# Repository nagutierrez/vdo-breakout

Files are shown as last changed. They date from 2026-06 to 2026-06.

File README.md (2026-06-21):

# VDO Breakout

A 4-gauge breakout board for VDO automotive instruments (e.g. Vision Black), with fused 12 V distribution, sender signal routing, and PWM dimming for LED backlighting.

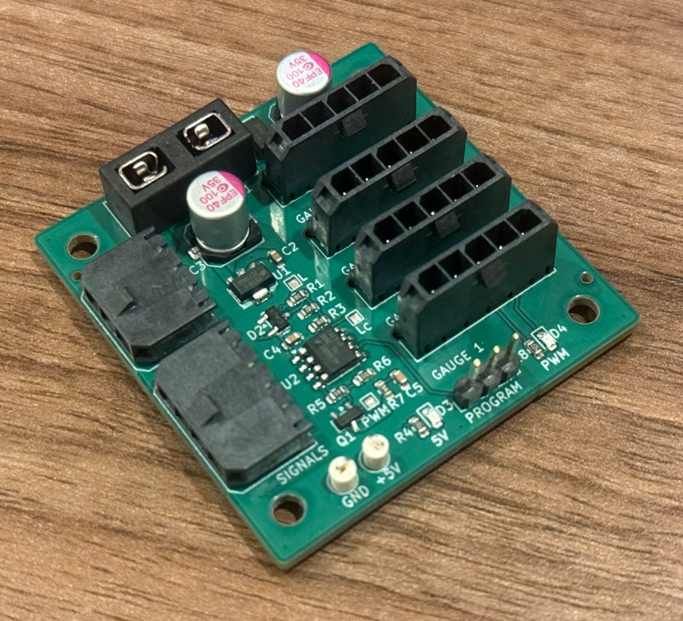
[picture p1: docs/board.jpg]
Assembled VDO Breakout PCB


## Overview

VDO gauges (e.g. Vision Black) terminate in **4–5 individual spade connectors**, not a single harness plug: **2 or 3 for the gauge** (12v power, ground, and usually a sender/sense) plus **2 for the bulb** (Light+, Light−). Wiring these directly in a custom dash in place is tedious.

This board consolidates those spade connections into four gauge ports (Molex Micro-Fit) plus dedicated power and signal headers — one harness per gauge instead of a handful of loose spades.

**LED backlighting** does not dim with a stock rheostat alone. An **ATtiny402** reads the vehicle dimmer input and PWM-switches the shared **Light−** return via an **IRLML2502** MOSFET so LED backlights track the dash lighting level.

```mermaid
flowchart LR
  Rheostat["Vehicle rheostat"] --> ADC["ATtiny402 ADC"]
  ADC --> PWM["PWM output"]
  PWM --> MOSFET["Q1 MOSFET"]
  MOSFET --> LightMinus["Gauge Light−"]
  Ign12V["Ignition 12V"] --> Gauges["4× gauge connectors"]
  Gauges --> SenseHeader["Signals header"]
```

## Features

- Individual Molex Micro-Fit 3.0 connectors for each gauge (J3–J6)
- Power input protection with mini blade fuse + 15 V TVS
- Single connector for all 4 gauge sender signals (J2)
- Rheostat input on power connector (J1)
- ATtiny402 PWM dimming on shared Light− (enables LED backlighting with rheostat-following brightness)
- UPDI programming header (J7); KiCad sources + production files in [`hardware/`](hardware/)

### Gauge connectors J3–J6

Molex 43650-0515 (one per gauge). PCB silk: `L−  L+  GND  12V  S^N`

| Pin | Signal |
| --- | --- |
| 1 | Sense (sender) |
| 2 | +12V (ignition-switched gauge power) |
| 3 | GND |
| 4 | Light+ |
| 5 | Light− (PWM-switched) |

J3 = Gauge 1 … J6 = Gauge 4.

### Power J1

Molex 43650-0300

| Pin | Signal |
| --- | --- |
| 1 | Lighting rheostat |
| 2 | GND |
| 3 | Ignition 12V |

### Dimming

Rheostat-following dimming on J1 pin 1 only works when the vehicle dimmer is wired **high-side** — the rheostat sits between the lighting supply and the bulbs. Brightness increases as voltage on pin 1 rises.

If the stock dimmer is **low-side** (between bulbs and ground), do not connect it to J1 for dimming. The voltage is inverted (full brightness ≈ 0 V, dimmest ≈ supply voltage) and indistinguishable at 0 V, where both full brightness and lights-off read ~0 V.

For low-side vehicles, add a separate potentiometer near the board, wired as a high-side divider between the lighting supply and J1 pin 1 (with GND on J1 pin 2), to dim the gauge backlights independently of the stock dash dimmer.

### Signals J2

Molex 43650-0400

| Pin | Signal |
| --- | --- |
| 1 | Sense 1 |
| 2 | Sense 2 |
| 3 | Sense 3 |
| 4 | Sense 4 |

### Program J7

2.54 mm pin header

| Pin | Signal |
| --- | --- |
| 1 | UPDI |
| 2 | GND |
| 3 | +5V |

## Building the board

- Open design: [`hardware/VDO Breakout.kicad_pro`](hardware/VDO%20Breakout.kicad_pro) (KiCad 10)
- BOM: [`hardware/production/bom.csv`](hardware/production/bom.csv) (LCSC part numbers included)
- Gerbers: [`hardware/production/VDO_Breakout.zip`](hardware/production/VDO_Breakout.zip)
- Pick-and-place: [`hardware/production/positions.csv`](hardware/production/positions.csv)

Open items:

- Fuse rating (F1) is not specified in the BOM — choose based on total gauge load.
- LDO is listed as HT75xx; confirm 5 V variant when ordering.

## Firmware

PlatformIO project in [`firmware/`](firmware/). The **ATtiny402** reads the vehicle dimmer on **PA6** (ADC) and PWM-switches gauge Light− on **PA1**.

Two build profiles: `ATtiny402` (incandescent fade timings) and `ATtiny402_LED` (faster fades for LED backlights). Program via UPDI on J7 — see the [firmware README](firmware/README.md) for build and flash instructions.

## Repository layout

```
hardware/     KiCad schematic, PCB, and production outputs
firmware/     ATtiny402 dimming firmware (PlatformIO)
```

## License

- **Hardware** ([`hardware/`](hardware/)): [CC BY-NC-SA 4.0](https://creativecommons.org/licenses/by-nc-sa/4.0/) — non-commercial use; derivatives must use the same license.
- **Firmware** ([`firmware/`](firmware/)): [MIT](firmware/LICENSE)

See [LICENSE.md](LICENSE.md) for details.

## Disclaimer

This is an automotive electrical project. Use at your own risk. Verify all wiring against your vehicle and gauge documentation before connecting power.

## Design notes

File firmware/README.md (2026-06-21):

# VDO Breakout Firmware

ATtiny402 firmware for gauge backlight dimming on the [VDO Breakout](../README.md) board.

Reads a 0–5 V (scaled from 0-12 V) vehicle dimmer signal on **PA6**, outputs PWM on **PA1** to drive the shared Light− MOSFET. Includes soft fade on startup/shutdown and brownout protection when board power is cut. The dimmer input expects a high-side rheostat signal; low-side vehicles need a local pot — see [Dimming](../README.md#dimming) in the project README.

## Build profiles

| Environment | Use case | Fade-in | Fade-out |
|---|---|---|---|
| `ATtiny402` | Incandescent gauge lighting | 1500 ms | 500 ms |
| `ATtiny402_LED` | LED gauge lighting | 300 ms | 200 ms |

## Build

```bash
cd firmware
pio run -e ATtiny402          # incandescent
pio run -e ATtiny402_LED      # LED
```

## Flash

Program via UPDI on J7 using an [Adafruit UPDI Friend](https://learn.adafruit.com/adafruit-updi-friend) (or compatible SerialUPDI adapter).

1. Set `upload_port` in `platformio.ini` to your serial device (`ls /dev/cu.usb*` on macOS).
2. Connect J7: UPDI → UPDI, GND → GND, +5V → PWR (or power the board separately).
3. Flash:

```bash
pio run -e ATtiny402 -t upload        # incandescent gauges
pio run -e ATtiny402_LED -t upload    # LED gauges
```

4. Burn BOD fuse once per chip (enables 4.3 V brown-out detector):

```bash
pio run -t fuses -e ATtiny402
```

## Bench tuning

Adjust `ADC_MIN` / `ADC_MAX` in `include/config.h` if the dimmer range doesn't feel right. If PWM still glitches on power cut, try raising `VDD_SHUTDOWN_MV` slightly (e.g. 4550–4600).

Licensed under the MIT License — see [LICENSE](LICENSE).

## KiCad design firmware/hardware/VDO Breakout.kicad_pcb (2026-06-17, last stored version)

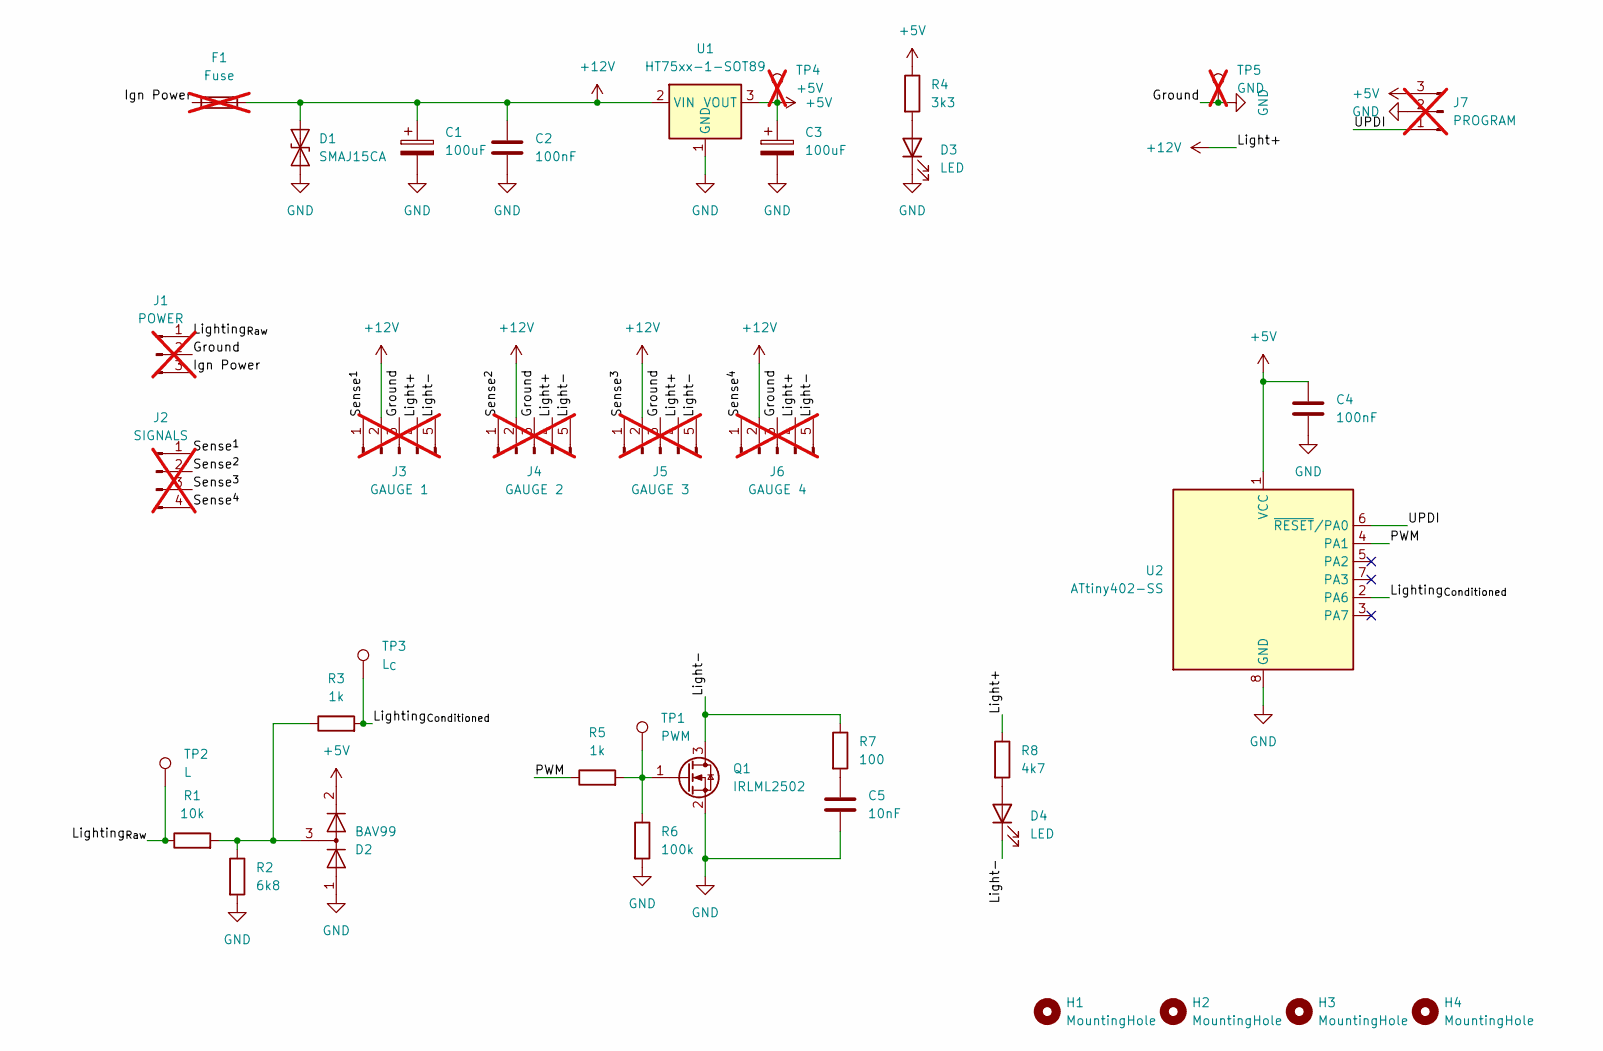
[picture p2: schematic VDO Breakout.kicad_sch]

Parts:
C1, C3: 100uF; C_Elec_6.3x7.7; LCSC C3035877
C2, C4: 100nF; C_0603_1608Metric; LCSC C14663
C5: 10nF; C_0603_1608Metric; LCSC C57112
D1: SMAJ15CA; D_SMA; LCSC C19077536
D2: BAV99; SOT-23; LCSC C2500
D3, D4: LED; LED_0603_1608Metric; LCSC C2286
F1: Fuse; Fuseholder_Blade_Mini_Keystone_3568; Digikey 3568; not fitted
H1, H2, H3, H4: MountingHole; MountingHole_3.2mm_M3
J1: POWER; Molex_Micro-Fit_3.0_43650-0300_1x03_P3.00mm_Horizontal; Digikey 0436500300; not fitted
J2: SIGNALS; Molex_Micro-Fit_3.0_43650-0400_1x04_P3.00mm_Horizontal; Digikey 0436500401; not fitted
J3: GAUGE 1; Molex_Micro-Fit_3.0_43650-0515_1x05_P3.00mm_Vertical; Digikey 0436500515; not fitted
J4: GAUGE 2; Molex_Micro-Fit_3.0_43650-0515_1x05_P3.00mm_Vertical; Digikey 0436500515; not fitted
J5: GAUGE 3; Molex_Micro-Fit_3.0_43650-0515_1x05_P3.00mm_Vertical; Digikey 0436500515; not fitted
J6: GAUGE 4; Molex_Micro-Fit_3.0_43650-0515_1x05_P3.00mm_Vertical; Digikey 0436500515; not fitted
J7: PROGRAM; PinHeader_1x03_P2.54mm_Vertical; Digikey 61300311121; not fitted
Q1: IRLML2502; SOT-23; LCSC C2589
R1: 10k; R_0603_1608Metric; LCSC C25804
R2: 6k8; R_0603_1608Metric; LCSC C23212
R3, R5: 1k; R_0603_1608Metric; LCSC C21190
R4: 3k3; R_0603_1608Metric; LCSC C22978
R6: 100k; R_0603_1608Metric; LCSC C25803
R7: 100; R_0603_1608Metric; LCSC C22775
R8: 4k7; R_0603_1608Metric; LCSC C23162
TP1: PWM; TestPoint_Pad_1.0x1.0mm
TP2: L; TestPoint_Pad_1.0x1.0mm
TP3: L_{C}; TestPoint_Pad_1.0x1.0mm
TP4: +5V; TestPoint_Loop_D2.50mm_Drill1.0mm; Digikey 5002; not fitted
TP5: GND; TestPoint_Loop_D2.50mm_Drill1.0mm; Digikey 5002; not fitted
U1: HT75xx-1-SOT89; SOT-89-3; Part C16106; LCSC C16106
U2: ATtiny402-SS; SOIC-8_3.9x4.9mm_P1.27mm; LCSC C2053235

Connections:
+5V: C3.1, C4.2, D2.2 (A), J7.3, R4.1, TP4.1 (1_1), U1.3 (VOUT), U2.1 (VCC)
+12V: C1.1, C2.1, D1.2 (A2), F1.2, J3.2, J3.4, J4.2, J4.4, J5.2, J5.4, J6.2, J6.4, R8.1, U1.2 (VIN)
/Ign Power: F1.1, J1.3
/Light-: D4.1 (K), J3.5, J4.5, J5.5, J6.5, Q1.3 (D), R7.1
/Lighting_{Conditioned}: R3.2, TP3.1 (1_1), U2.2 (PA6)
/Lighting_{Raw}: J1.1, R1.1, TP2.1 (1_1)
/PWM: R5.1, U2.4 (PA1)
/Sense^{1}: J2.1, J3.1
/Sense^{2}: J2.2, J4.1
/Sense^{3}: J2.3, J5.1
/Sense^{4}: J2.4, J6.1
/UPDI: J7.1, U2.6 (~RESET/PA0)
GND: C1.2, C2.2, C3.2, C4.1, C5.1, D1.1 (A1), D2.1 (K), D3.1 (K), J1.2, J3.3, J4.3, J5.3, J6.3, J7.2, Q1.2 (S), R2.2, R6.2, TP5.1 (1_1), U1.1 (GND), U2.8 (GND)
unnamed: C5.2, R7.2
unnamed: D2.3 (K), R1.2, R2.1, R3.1
unnamed: D3.2 (A), R4.2
unnamed: D4.2 (A), R8.2
unnamed: Q1.1 (G), R5.2, R6.1, TP1.1 (1_1)

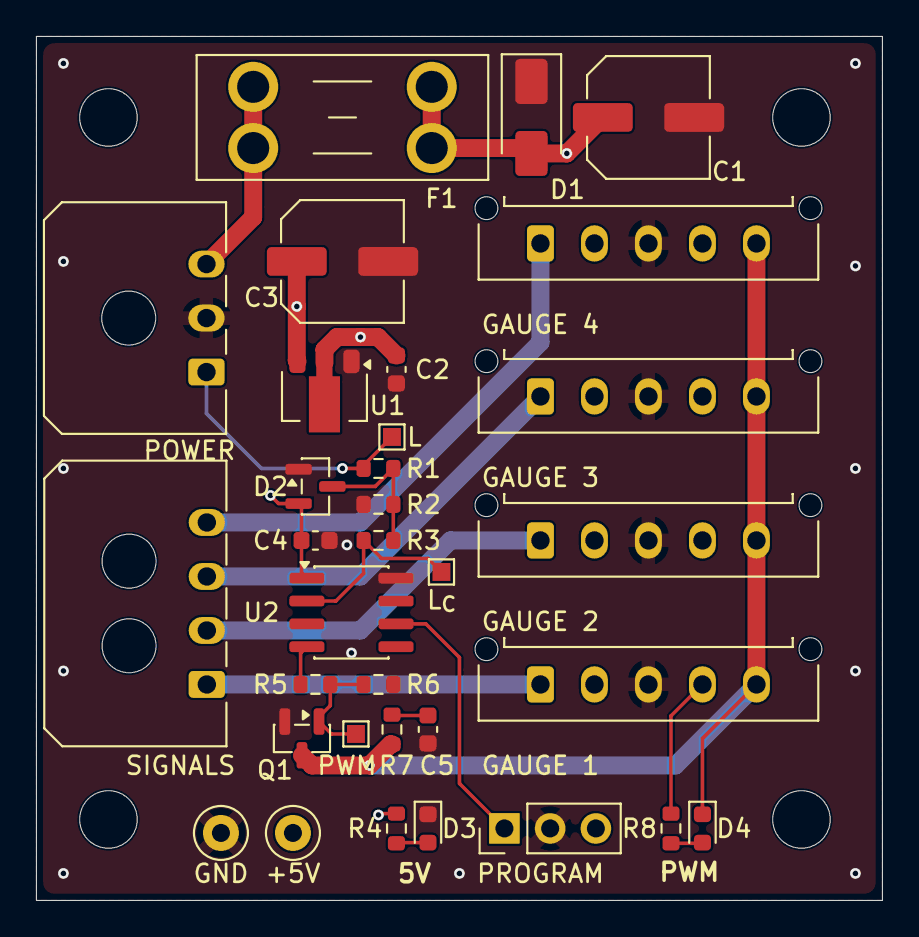
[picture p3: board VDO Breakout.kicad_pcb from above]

Board: 4 copper layers, 47.0 x 48.0 mm, 37 parts (0 on the bottom side), 18 nets.

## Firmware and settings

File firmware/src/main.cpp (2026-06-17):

#include <Arduino.h>

#include "adc_input.h"
#include "config.h"
#include "fader.h"
#include "power_monitor.h"
#include "pwm_output.h"

void setup() {
  adc_input_init();
  power_monitor_init();
  pwm_output_init();
  fader_init();
}

void loop() {
  if (!power_is_stable()) {
    pwm_output_set_duty(0);
    delay(LOOP_INTERVAL_MS);
    return;
  }

  adc_input_update();
  fader_update(adc_brightness(), adc_filtered_raw());
  delay(LOOP_INTERVAL_MS);
}

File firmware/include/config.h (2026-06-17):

#pragma once

#include <Arduino.h>

// PA6: conditioned 0-5 V dimmer input. PA1: PWM to MOSFET gate. PA0: UPDI only.
constexpr uint8_t PIN_ADC = PIN_PA6;
constexpr uint8_t PIN_PWM = PIN_PA1;

// Hysteresis thresholds on 10-bit ADC counts (~2% / ~4% of full scale).
constexpr uint16_t ADC_OFF_THRESHOLD = 20;
constexpr uint16_t ADC_ON_THRESHOLD = 41;

// Map usable dimmer range to PWM duty; tune on bench if needed.
constexpr uint16_t ADC_MIN = 20;
constexpr uint16_t ADC_MAX = 1000;

constexpr uint8_t ADC_EMA_SHIFT = 4;

constexpr uint16_t SIGNAL_OFF_DEBOUNCE_MS = 100;
constexpr uint16_t LOOP_INTERVAL_MS = 20;

// Force PWM off when supply sags during capacitor discharge on power cut.
constexpr uint16_t VDD_SHUTDOWN_MV = 4500;

#ifndef LOAD_PROFILE_INCANDESCENT
#ifndef LOAD_PROFILE_LED
#define LOAD_PROFILE_INCANDESCENT
#endif
#endif

#if defined(LOAD_PROFILE_LED)
constexpr uint16_t FADE_IN_MS = 300;
constexpr uint16_t FADE_OUT_MS = 200;
#else
constexpr uint16_t FADE_IN_MS = 1500;
constexpr uint16_t FADE_OUT_MS = 500;
#endif

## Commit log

2026-06-17 Initial commit; hardware and project structure
    [VDO Breakout.kicad_pcb, VDO Breakout.kicad_sch, bom.csv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]
2026-06-17 Add initial implementation of firmware
    [VDO Breakout.kicad_pcb, VDO Breakout.kicad_sch, bom.csv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]
2026-06-17 Add ATtiny402 gauge dimming firmware with LED/incandescent profiles and brownout protection.
    [VDO Breakout.kicad_pcb, VDO Breakout.kicad_sch, bom.csv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]
2026-06-17 Remove unecessary and vaguely incorrect documentation, add iamge of assembled board
